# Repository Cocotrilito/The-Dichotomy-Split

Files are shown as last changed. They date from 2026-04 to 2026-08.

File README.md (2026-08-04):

# The -Dichotomy- Split

<p align="center">
  demo
</p>

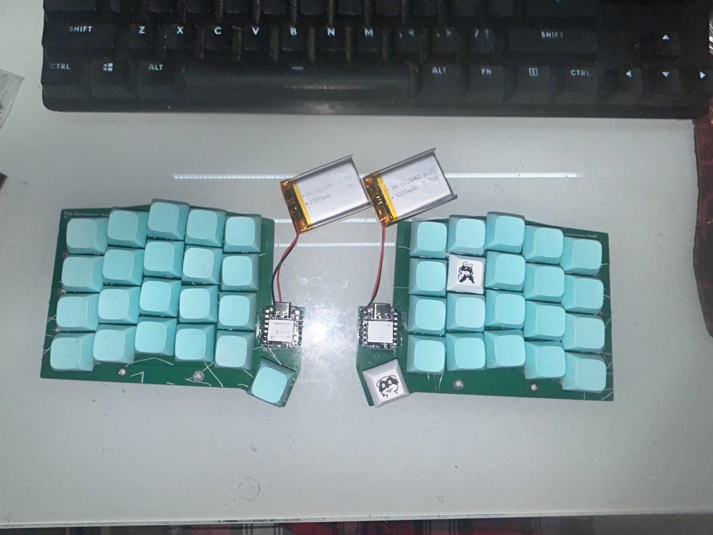
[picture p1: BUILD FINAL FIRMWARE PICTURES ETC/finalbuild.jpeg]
final build


[Download Final Firmware](<BUILD FINAL FIRMWARE PICTURES ETC/FinalFirmware.zip>)

An Split keyboard, created to understand new things like matrix and wireless things, and also from the feeling of being split, Im trying to become someone new but im still stuck in this hole, A tool for the transition... a bridge out of the hole.

## The reason behind this project...
Initially I wanted to prove myself I could go a little more deeper, what I mean Is that I had already made a macropad as my first hackclub project 4 months ago, and the split keyboard was the logical step, when I started with KiCad Fusion and coding.
everything was really hard im not saying today it isnt, but compared to how much I struggled 4 months ago, I can proudly say I have learned, and not just a little, but A LOT, and as I am writing this, throught my headphones KUNGFUPANDA theme song is blasting my
ears, this is the same song I used to play back and back again 4 months ago, and you see 4 months ago I was lost (im still kinda but not as I was), I was heartbroken, and without an actual purpose, and I saw I video on my feed talking about blueprint, this made
me really curious, and I started learning, and now here I am, well I wanted to learn about ZMK in my macropad I only did the QMK firmware but I really wanted to tryout ZMK, and was really cool!, also I wanted to make the projects that I thought were impossible
and to the Isaac of 4 months ago... Thanks!, you have really changed your life, and to the future Isaac... How are you doing? was it all worth it?... thanks for reading if you did! <3

## zmk repo
[ZMK code](https://github.com/Cocotrilito/zmk-config)
## layout


## Schematic Overview
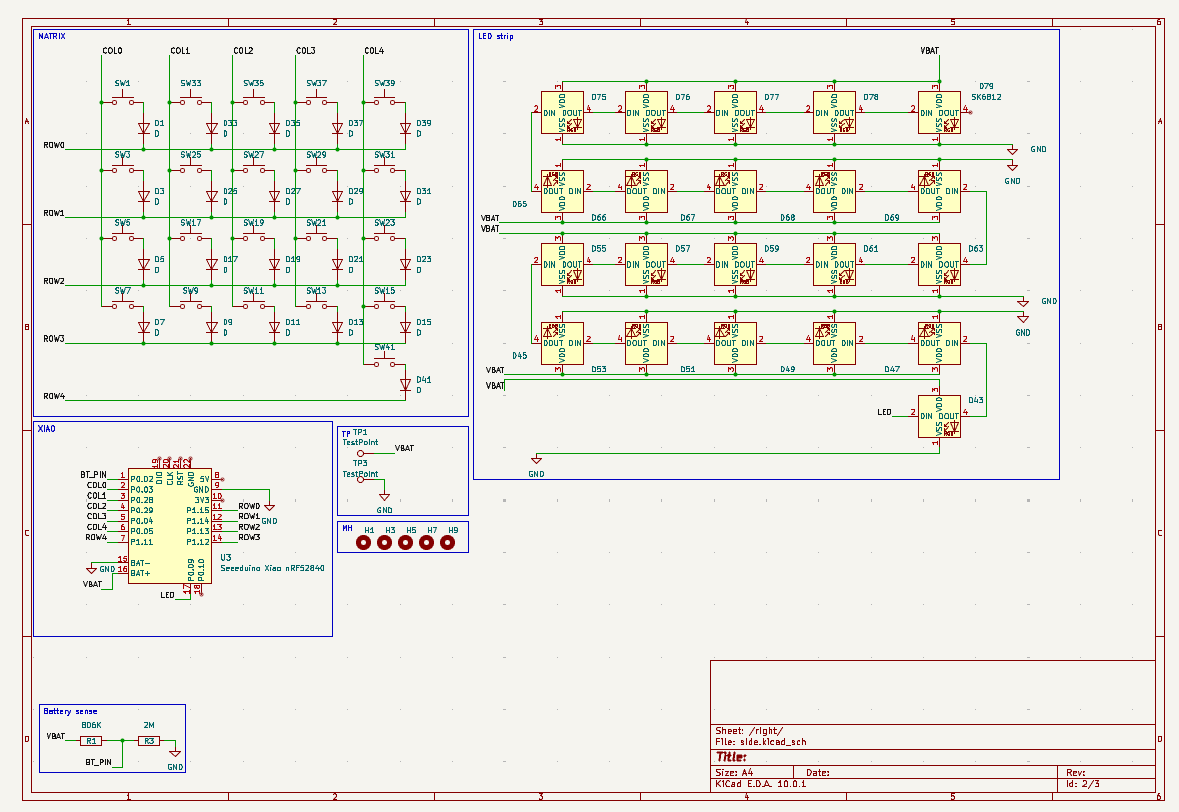
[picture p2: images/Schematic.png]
Schematic left


## PCB

<table>
  <tr>
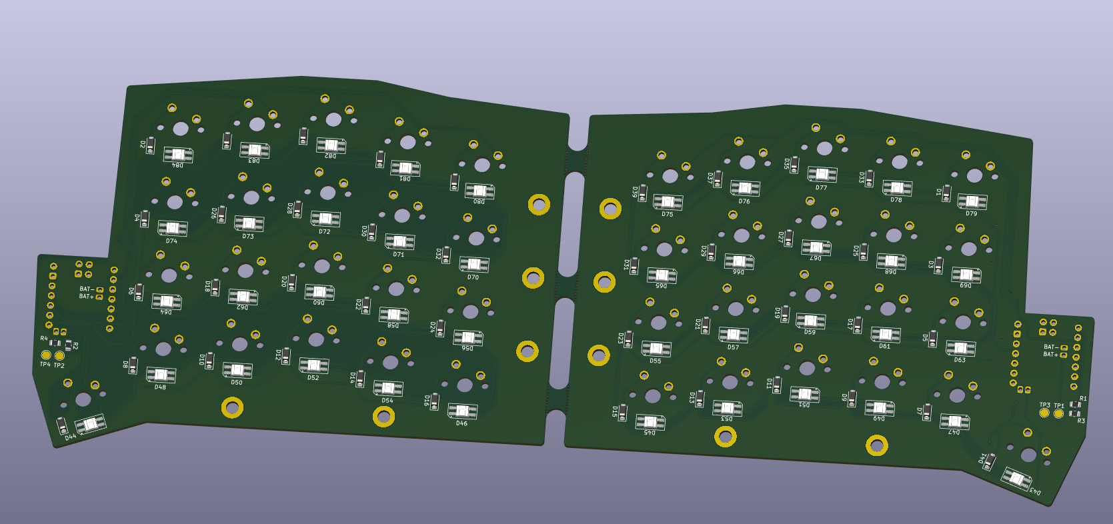
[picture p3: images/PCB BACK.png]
    <td align="center"><br><b>PCB OVERVIEW</b></td>
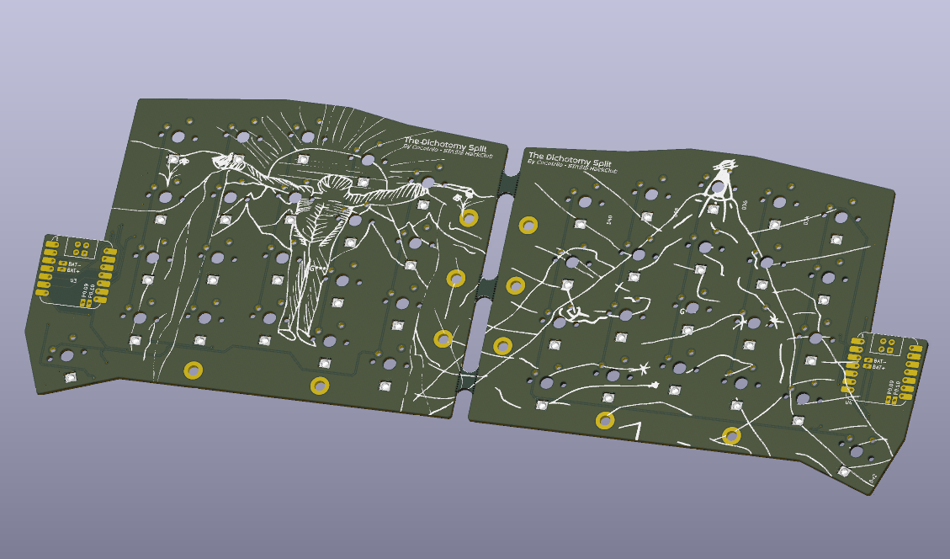
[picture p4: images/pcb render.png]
    <td align="center"><br><b>Render</b></td>
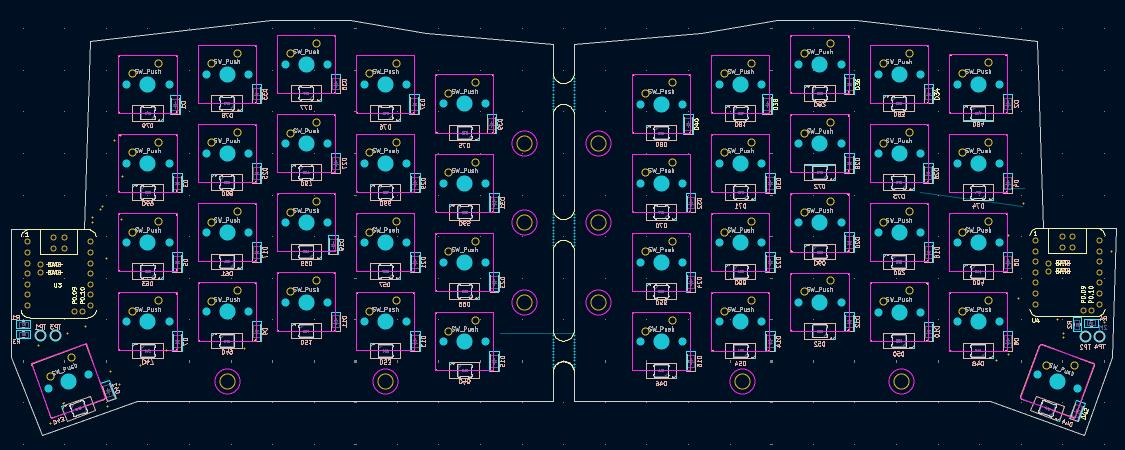
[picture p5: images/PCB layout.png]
    <td align="center"><br><b>PCB layout</b></td>
  </tr>
  <tr>
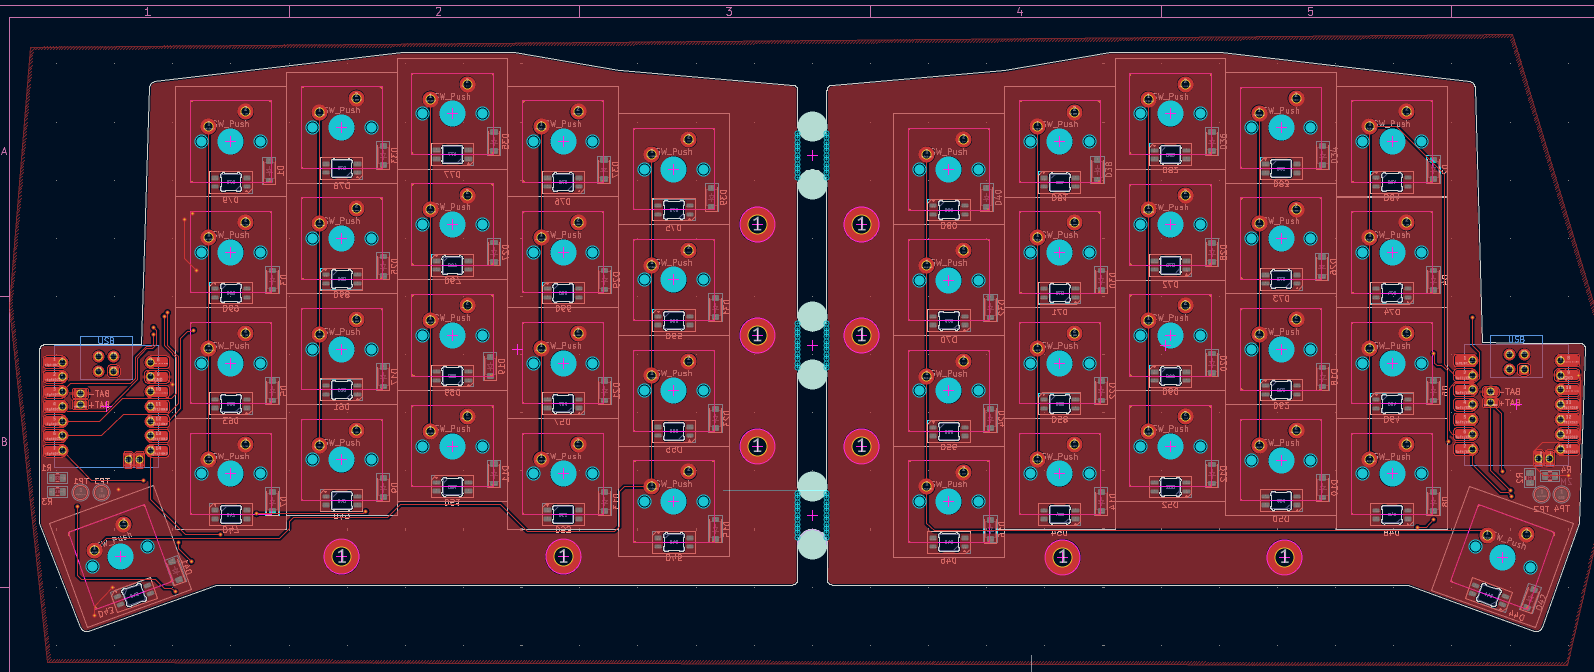
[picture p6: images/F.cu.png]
    <td align="center"><br><b>PCB Top</b></td>
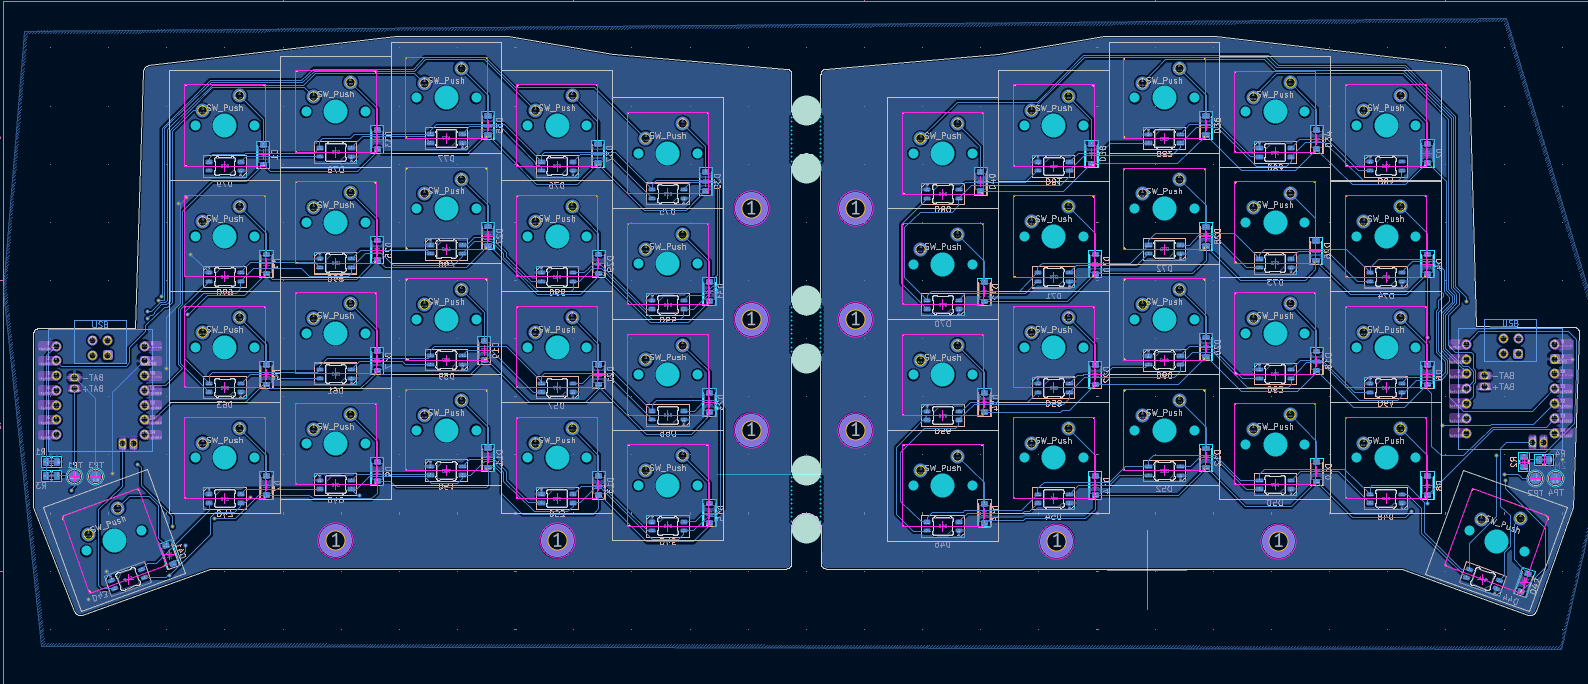
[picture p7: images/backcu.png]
    <td align="center"><br><b>PCB Back</b></td>
    <td></td>
  </tr>
</table>

## CAD Render
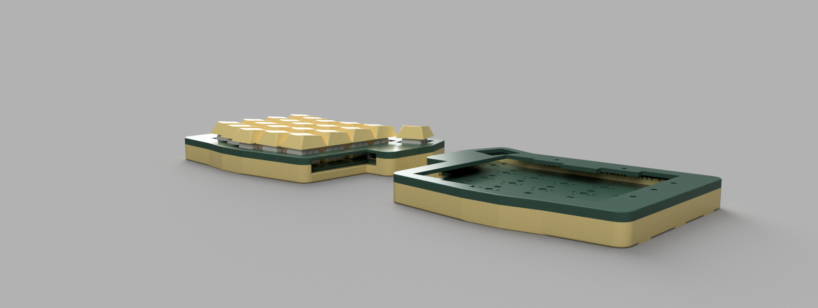
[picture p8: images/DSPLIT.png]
DSPLIT OVERVIEW

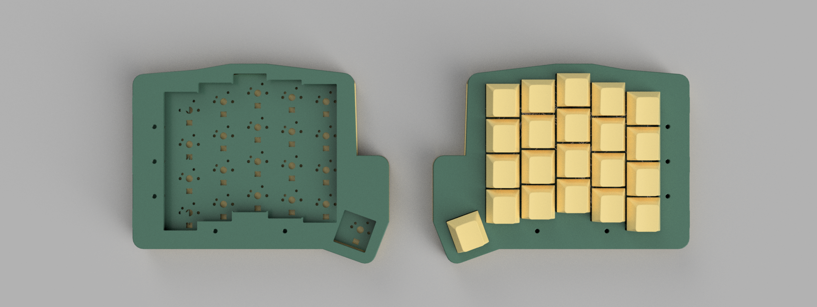
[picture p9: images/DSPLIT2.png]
DSPLIT TOP

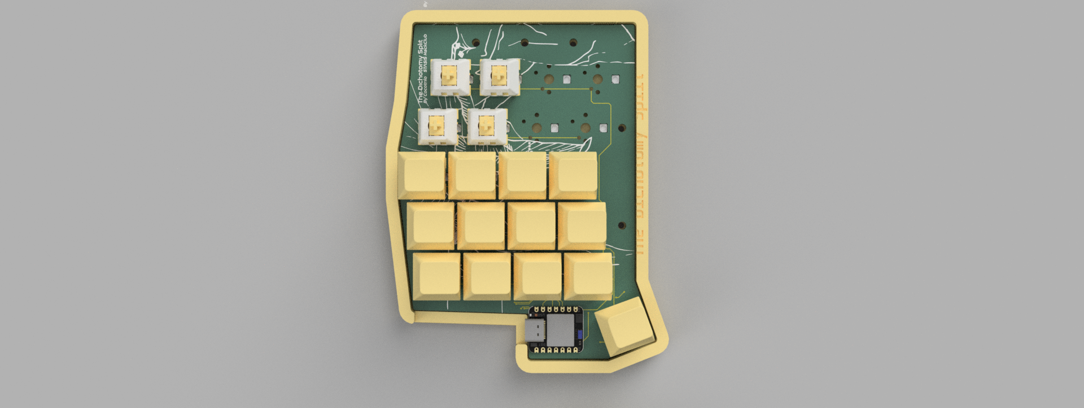
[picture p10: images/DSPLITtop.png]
DSPLIT CUT


## BOM

| Name | Purpose | Qty | Total Cost (USD) | Link |
| :--- | :--- | :---: | :---: | :--- |
| **1N4148W SOD-123** | Efficiency for pins in matrix, also avoids ghosting | 1 (set) | $1.31 | [AliExpress](https://www.aliexpress.us/item/3256810466885186.html) |
| **XDA Profile PBT Keycaps** | Ergonomics and feel | 1 (set) | $11.83 | [AliExpress](https://www.aliexpress.us/item/3256810402164930.html) |
| **Outemu Silent Switches** | Mechanical input (Tactile/Silent) | 1 (set) | $7.55 | [AliExpress](https://www.aliexpress.us/item/3256811652574937.html) |
| **LEDs SK6812 MINI-E** | Per-key RGB lighting (WS2812B compatible) | 1 (set) | $4.83 | [AliExpress](https://www.aliexpress.us/item/3256810305129996.html) |
| **PCB Manufacturing** | Custom designed PCBs for the split layout | 1 (set) | $14.60 | [JLCPCB] |
| **Seeed Studio XIAO nRF52840** | Main microcontrollers with BLE for wireless | 2 | $37.98 | [Amazon](https://www.amazon.com/gp/product/B09T9VVQG7/) |

## SPECIAL THANKS!
Thanks for reading! made possible with [STASIS by HackClubbers](http://stasis.hackclub.com/)

## You might also like!
[Voyager Panel](https://github.com/Cocotrilito/Voyager-Panel)
[HALO-0](https://github.com/Cocotrilito/HALO-0)

## final thanks :3
By cocotrilo made with luv (THIS ONE WAS WITH philosophical meaning) keep the grind <3

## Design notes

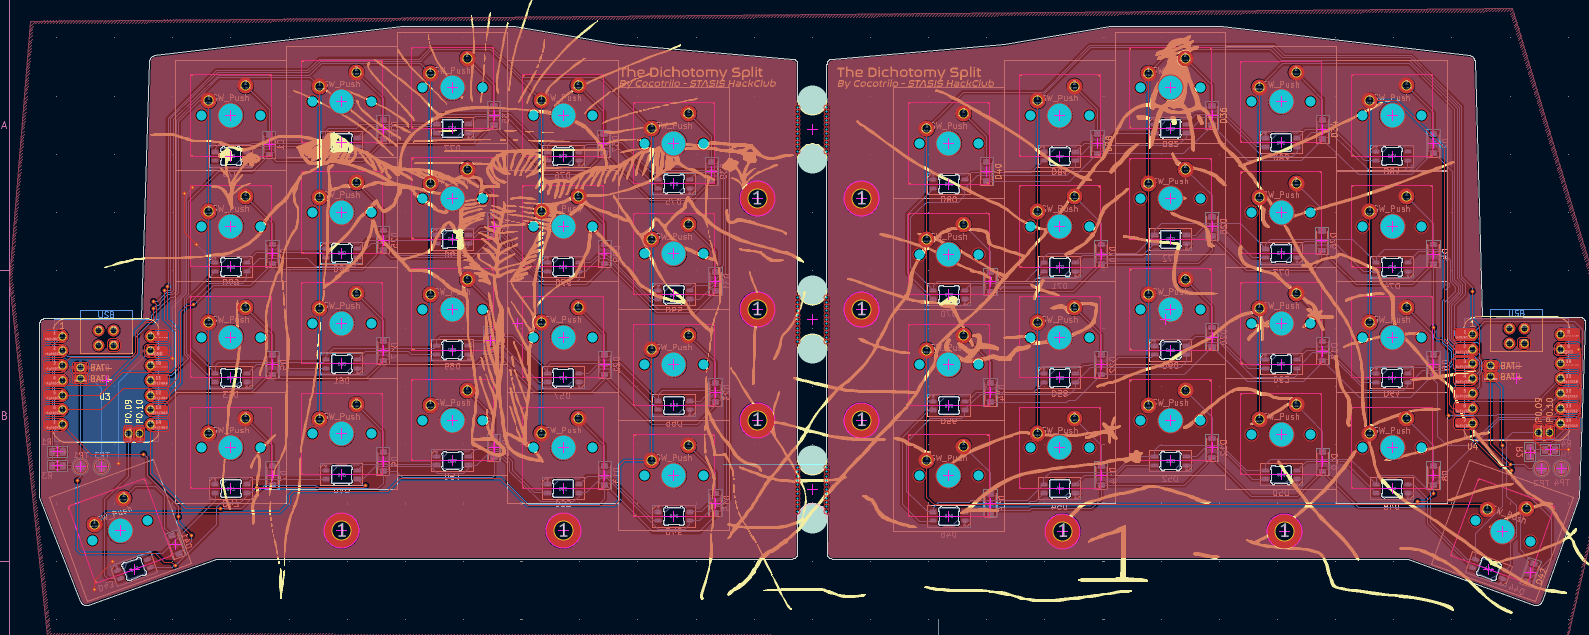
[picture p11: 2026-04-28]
images/overviewpcb.png

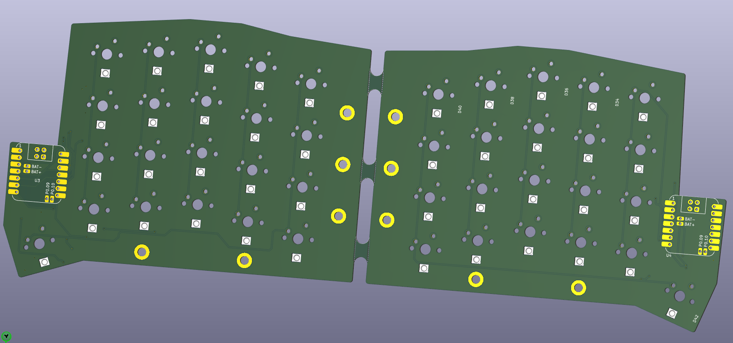
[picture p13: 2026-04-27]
images/PCB Front.png

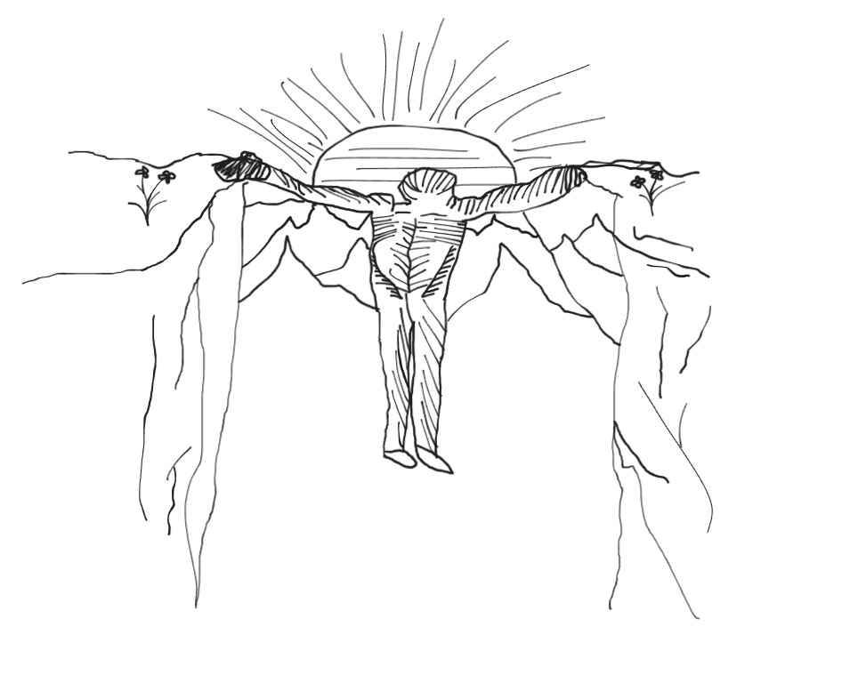
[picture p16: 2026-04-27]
images/art.png

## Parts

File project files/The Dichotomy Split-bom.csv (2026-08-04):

Name | Purpose | Quantity | Total Cost (USD) | Link | Distributor
1N4148W SOD-123 surface mount diode | Efficiency for pins in matrix, also avoids ghosting, and multiple inputs | 1 | 1.31 | https://www.aliexpress.us/item/3256810466885186.html?curPageLogUid=OGrmMMg8PsE2 | Aliexpress
Keycaps XDA PBT (50pcs) | Low-profile ergonomic keycaps for the switch matrix. | 1 | 9.24 | https://www.aliexpress.us/item/3256810402164930.html?mp=1 | Aliexpress
Mechanical Switches (50pcs) | Tactile input switches for the keyboard matrix. | 1 | 5.13 | https://www.aliexpress.us/item/3256811652574937.html?mp=1 | Aliexpress
LEDs SK6812 MINI-E (100pcs) | Per-key RGB lighting (WS2812B compatible protocol). | 1 | 4.83 | https://www.aliexpress.us/item/3256810305129996.html?mp=1 | Aliexpress
PCB Manufacturing (265x99mm) | Custom designed PCBs for the split layout | 1 | 14.60 |  | JLCPCB
Seeed Studio XIAO nRF52840 | Main microcontrollers with BLE for wireless split connectivity. | 2 | 37.98 | https://www.amazon.com/gp/product/B09T9VVQG7/ref=ox_sc_act_title_1?smid=A2OY3Y9CEYQQ5W | AMAZON
Resistor 2M Ohm 0805 (100pcs) | High-value resistor for the battery voltage divider circuit. | 1 | 3.05 | https://www.aliexpress.us/item/3256807764544932.html?mp=1 | Aliexpress
Resistor 806k Ohm 0805 (100pcs) | Precision resistor for the battery voltage divider circuit. | 1 | 3.05 | https://www.aliexpress.us/item/3256807764544932.html?mp=1 | Aliexpress

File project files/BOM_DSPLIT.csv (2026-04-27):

Part | Price | Quantity | Purpose | Link
Seeed Studio XIAO nRF52840 | 18.99 | 2 | Main microcontrollers with BLE for wireless split connectivity. | https://www.amazon.com/gp/product/B09T9VVQG7/ref=ox_sc_act_title_1?smid=A2OY3Y9CEYQQ5W
PCB Manufacturing (265x99mm) | 14.6 | 1 | Custom designed PCBs for the split layout
Keycaps XDA PBT (50pcs) | 9.24 | 1 | Low-profile ergonomic keycaps for the switch matrix. | https://www.aliexpress.us/item/3256810402164930.html?mp=1
Mechanical Switches (50pcs) | 5.13 | 1 | Tactile input switches for the keyboard matrix. | https://www.aliexpress.us/item/3256811652574937.html?mp=1
LEDs SK6812 MINI-E (100pcs) | 4.83 | 1 | Per-key RGB lighting (WS2812B compatible protocol). | https://www.aliexpress.us/item/3256810305129996.html?mp=1
Resistor 806k Ohm 0805 (100pcs) | 3.05 | 1 | Precision resistor for the battery voltage divider circuit. | https://www.aliexpress.us/item/3256807764544932.html?mp=1
Resistor 2M Ohm 0805 (100pcs) | 3.05 | 1 | High-value resistor for the battery voltage divider circuit. | https://www.aliexpress.us/item/3256807764544932.html?mp=1
 |  |  |  |  | Link

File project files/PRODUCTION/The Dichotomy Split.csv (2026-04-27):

Id | Designator | Footprint | Quantity | Comment | Supplier and ref
1 | D1, D2, D3, D4, D5, D6, D7, D8, D9, D10, D11, D12, D13, D14, D15, D16, D17, D18, D19, D20, D21, D22, D23, D24, D25, D26, D27, D28, D29, D30, D31, D32, D33, D34, D35, D36, D37, D38, D39, D40, D41, D42 | D_SOD-123 | 42 | D
2 | D43, D44, D45, D46, D47, D48, D49, D50, D51, D52, D53, D54, D55, D56, D57, D58, D59, D60, D61, D62, D63, D64, D65, D66, D67, D68, D69, D70, D71, D72, D73, D74, D75, D76, D77, D78, D79, D80, D81, D82, D83, D84 | LED_SK6812MINI-E_3.2x2.8mm_P1.5mm_ReverseMount | 42 | SK6812
3 | R1, R2 | R_0805_2012Metric | 2 | 806K
4 | R3, R4 | R_0805_2012Metric | 2 | 2M
5 | SW1, SW2, SW3, SW4, SW5, SW6, SW7, SW8, SW9, SW10, SW11, SW12, SW13, SW14, SW15, SW16, SW17, SW18, SW19, SW20, SW21, SW22, SW23, SW24, SW25, SW26, SW27, SW28, SW29, SW30, SW31, SW32, SW33, SW34, SW35, SW36, SW37, SW38, SW39, SW40, SW41, SW42 | SW_MX_1u | 42 | SW_Push
6 | TP1, TP2, TP3, TP4 | TestPoint_Pad_D2.0mm | 4 | TestPoint

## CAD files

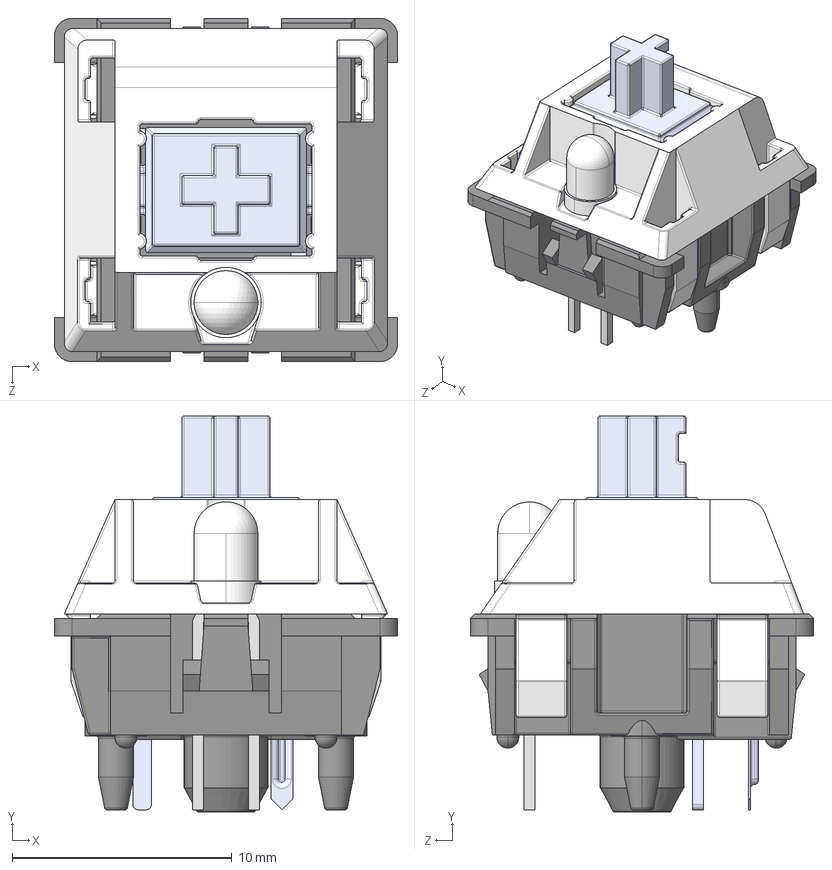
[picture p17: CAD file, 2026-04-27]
CAD/assets/cherry-mx-red-switch-1.snapshot.3/Cherry MX.STEP
15.6 x 18.0 x 15.6 mm
Bottom
Pulsador
Top
Pieza5^Cherry MX
Pin1
Pin2
Led 3mm_trans

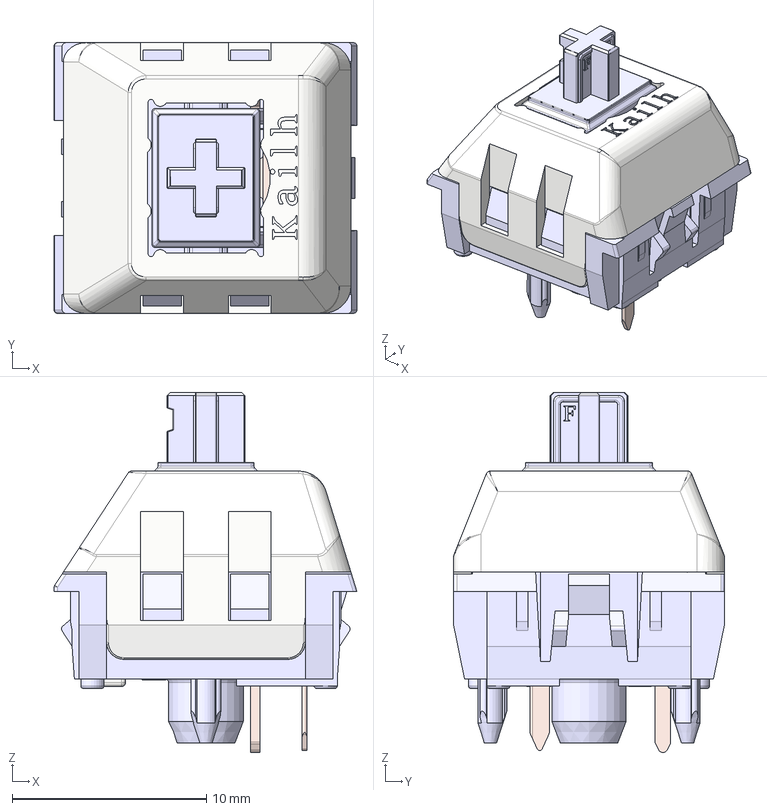
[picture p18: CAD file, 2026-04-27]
CAD/assets/kailh-polia-switch-cherry-mx-compatible-1.snapshot.1/Kailh Polia.step
15.6 x 14.0 x 18.5 mm
Housing
ThickContact
SpringContact
Stem
Lid

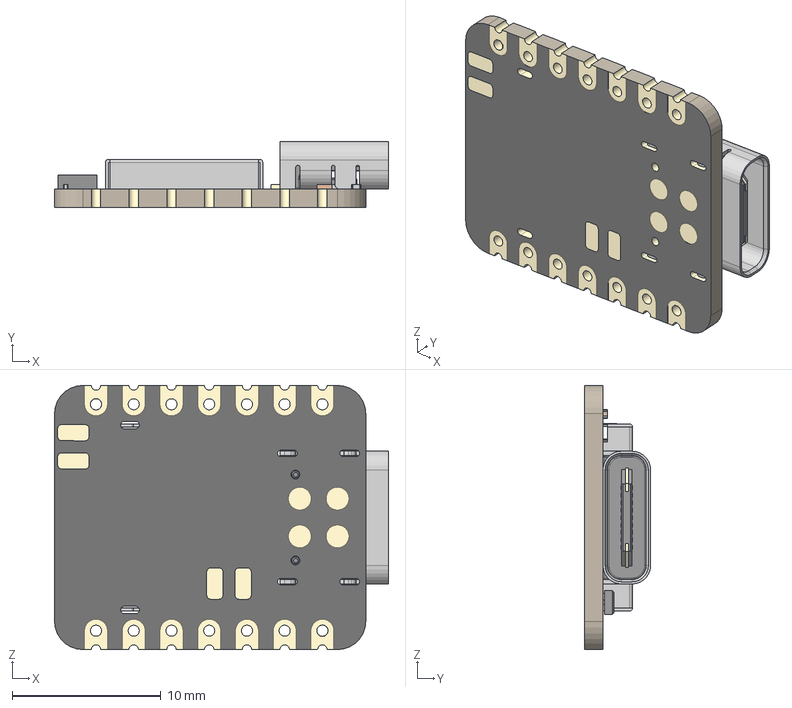
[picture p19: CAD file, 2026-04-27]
CAD/assets/seeed-studio-xiao-nrf52840-1.snapshot.5/XIAO-nRF52840 v15.step
22.5 x 4.46 x 17.8 mm
BOSS-EXTRUDE14_8_
BOSS-EXTRUDE7_4_
BOSS-EXTRUDE7_3_
BOSS-EXTRUDE14_4_
BOSS-EXTRUDE14_2_
BOSS-EXTRUDE14_11_
BOSS-EXTRUDE7_7_
BOSS-EXTRUDE14_9_
BOSS-EXTRUDE14_3_
BOSS-EXTRUDE14_7_
MIRROR2
BOSS-EXTRUDE14_5_
BOSS-EXTRUDE14_12_
BOSS-EXTRUDE7_8_
BOSS-EXTRUDE7_1_
BOSS-EXTRUDE14_10_
BOSS-EXTRUDE7_9_
BOSS-EXTRUDE14_6_
BOSS-EXTRUDE14_1_
BOSS-EXTRUDE7_6_
BOSS-EXTRUDE7_2_
CUT-EXTRUDE5
BOSS-EXTRUDE7_5_
Shield
Pins
CAP x 2
ANT1
Silkscreen
CAP 3
LED
USR
2 v1

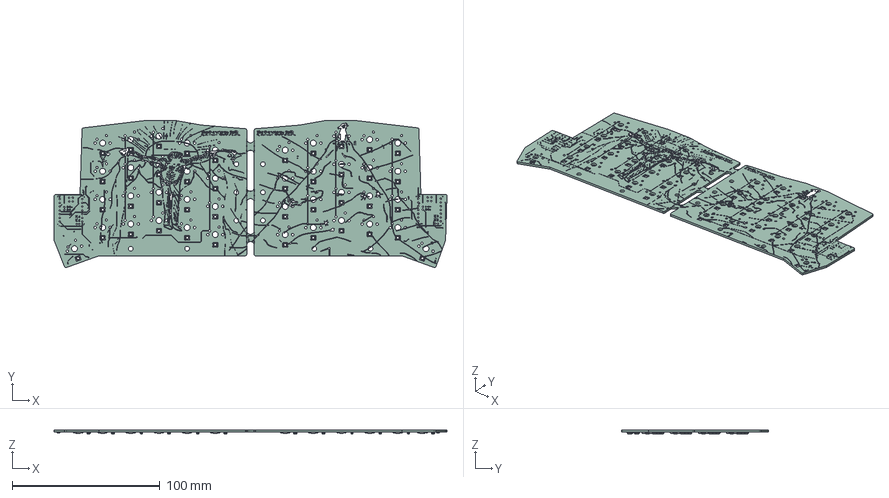
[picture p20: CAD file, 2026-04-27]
CAD/DSPLIT.step
265.9 x 99.6 x 2.93 mm
D_SOD-123 x 42
Pin1 x 42
Pin2 x 42
Pin3 x 42
Pin4 x 42
R_0805_2012Metric x 4
The Dichotomy Split_copper
The Dichotomy Split_via
The Dichotomy Split_silkscreen x 2
The Dichotomy Split_PCB

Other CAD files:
CAD/assets/cherry-mx-red-switch-1.snapshot.3/Cherry MX.IGS
CAD/assets/kailh-polia-switch-cherry-mx-compatible-1.snapshot.1/Kailh Polia.f3d

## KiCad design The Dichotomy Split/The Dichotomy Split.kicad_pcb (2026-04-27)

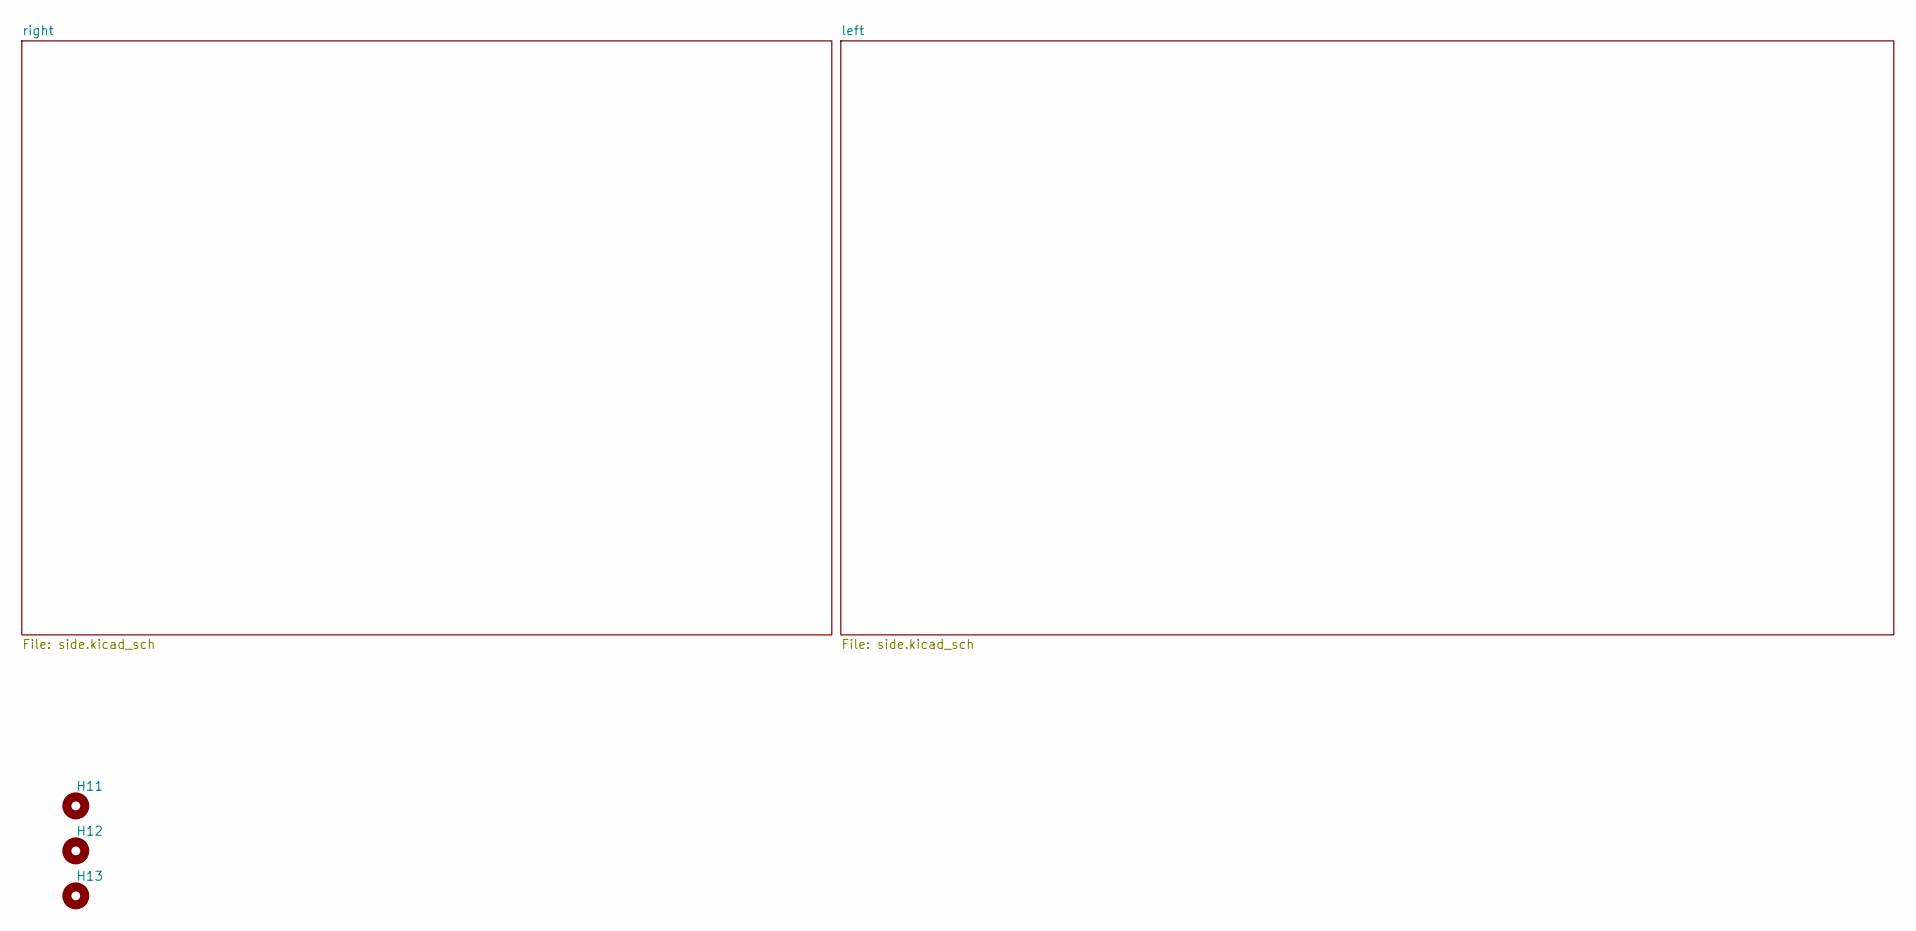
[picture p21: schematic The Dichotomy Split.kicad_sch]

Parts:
H11, H12, H13: MountingHole; mouse-bite-5mm-slot

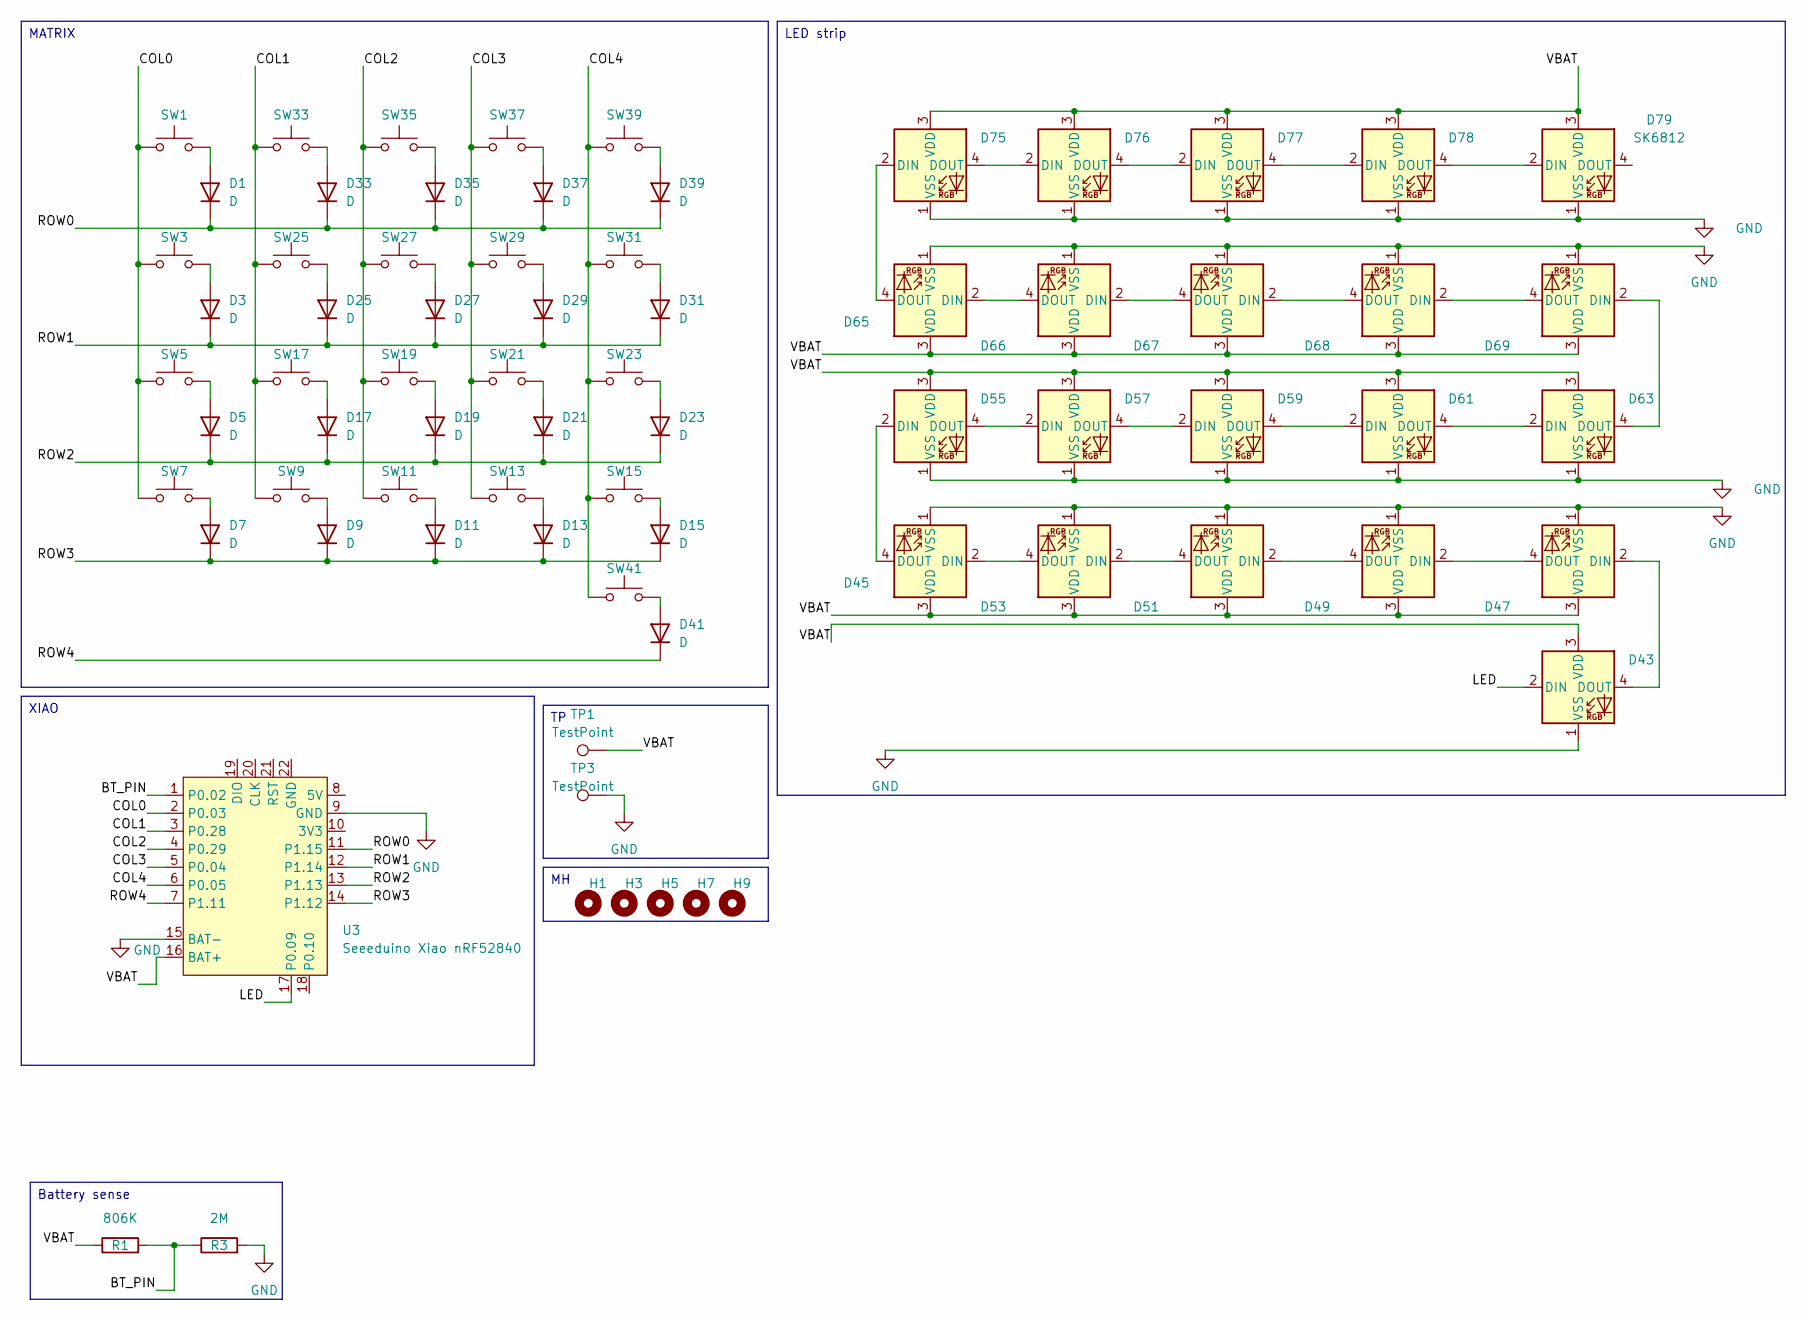
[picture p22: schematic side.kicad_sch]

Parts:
D1, D3, D5, D7, D9, D11, D13, D15, D17, D19, D21, D23, D25, D27, D29, D31, D33, D35, D37, D39, D41: D; D_SOD-123
D43, D45, D47, D49, D51, D53, D55, D57, D59, D61, D63, D65, D66, D67, D68, D69, D75, D76, D77, D78, D79: SK6812; LED_SK6812MINI-E_3.2x2.8mm_P1.5mm_ReverseMount
H1, H3, H5, H7, H9: MountingHole; MountingHole_3.2mm_M3_DIN965_Pad
R1: 806K; R_0805_2012Metric
R3: 2M; R_0805_2012Metric
SW1, SW3, SW5, SW7, SW9, SW11, SW13, SW15, SW17, SW19, SW21, SW23, SW25, SW27, SW29, SW31, SW33, SW35, SW37, SW39, SW41: SW_Push; SW_MX_1u
TP1, TP3: TestPoint; TestPoint_Pad_D2.0mm
U3: Seeeduino Xiao nRF52840; Xiao_nRF52840_ACH

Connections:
/right/BT_PIN: R1.2, R3.1, U3.1 (P0.02)
/right/COL0: SW1.1, SW3.1, SW5.1, SW7.1, U3.2 (P0.03)
/right/COL1: SW9.1, SW17.1, SW25.1, SW33.1, U3.3 (P0.28)
/right/COL2: SW11.1, SW19.1, SW27.1, SW35.1, U3.4 (P0.29)
/right/COL3: SW13.1, SW21.1, SW29.1, SW37.1, U3.5 (P0.04)
/right/COL4: SW15.1, SW23.1, SW31.1, SW39.1, SW41.1, U3.6 (P0.05)
/right/LED: D43.2 (DIN), U3.17 (P0.09)
/right/ROW0: D1.1 (K), D33.1 (K), D35.1 (K), D37.1 (K), D39.1 (K), U3.11 (P1.15)
/right/ROW1: D3.1 (K), D25.1 (K), D27.1 (K), D29.1 (K), D31.1 (K), U3.12 (P1.14)
/right/ROW2: D5.1 (K), D17.1 (K), D19.1 (K), D21.1 (K), D23.1 (K), U3.13 (P1.13)
/right/ROW3: D7.1 (K), D9.1 (K), D11.1 (K), D13.1 (K), D15.1 (K), U3.14 (P1.12)
/right/ROW4: D41.1 (K), U3.7 (P1.11)
/right/VBAT: D43.3 (VDD), D45.3 (VDD), D47.3 (VDD), D49.3 (VDD), D51.3 (VDD), D53.3 (VDD), D55.3 (VDD), D57.3 (VDD), D59.3 (VDD), D61.3 (VDD), D63.3 (VDD), D65.3 (VDD), D66.3 (VDD), D67.3 (VDD), D68.3 (VDD), D69.3 (VDD), D75.3 (VDD), D76.3 (VDD), D77.3 (VDD), D78.3 (VDD), D79.3 (VDD), R1.1, TP1.1 (1_1), U3.16 (BAT+)
GND: D43.1 (VSS), D45.1 (VSS), D47.1 (VSS), D49.1 (VSS), D51.1 (VSS), D53.1 (VSS), D55.1 (VSS), D57.1 (VSS), D59.1 (VSS), D61.1 (VSS), D63.1 (VSS), D65.1 (VSS), D66.1 (VSS), D67.1 (VSS), D68.1 (VSS), D69.1 (VSS), D75.1 (VSS), D76.1 (VSS), D77.1 (VSS), D78.1 (VSS), D79.1 (VSS), R3.2, TP3.1 (1_1), U3.9 (GND), U3.15 (BAT-); also elsewhere on the board
unnamed: D1.2 (A), SW1.2
unnamed: D3.2 (A), SW3.2
unnamed: D5.2 (A), SW5.2
unnamed: D7.2 (A), SW7.2
unnamed: D9.2 (A), SW9.2
unnamed: D11.2 (A), SW11.2
unnamed: D13.2 (A), SW13.2
unnamed: D15.2 (A), SW15.2
unnamed: D17.2 (A), SW17.2
unnamed: D19.2 (A), SW19.2
unnamed: D21.2 (A), SW21.2
unnamed: D23.2 (A), SW23.2
unnamed: D25.2 (A), SW25.2
unnamed: D27.2 (A), SW27.2
unnamed: D29.2 (A), SW29.2
unnamed: D31.2 (A), SW31.2
unnamed: D33.2 (A), SW33.2
unnamed: D35.2 (A), SW35.2
unnamed: D37.2 (A), SW37.2
unnamed: D39.2 (A), SW39.2
unnamed: D41.2 (A), SW41.2
unnamed: D43.4 (DOUT), D47.2 (DIN)
unnamed: D45.2 (DIN), D53.4 (DOUT)
unnamed: D45.4 (DOUT), D55.2 (DIN)
unnamed: D47.4 (DOUT), D49.2 (DIN)
unnamed: D49.4 (DOUT), D51.2 (DIN)
unnamed: D51.4 (DOUT), D53.2 (DIN)
unnamed: D55.4 (DOUT), D57.2 (DIN)
unnamed: D57.4 (DOUT), D59.2 (DIN)
unnamed: D59.4 (DOUT), D61.2 (DIN)
unnamed: D61.4 (DOUT), D63.2 (DIN)
unnamed: D63.4 (DOUT), D69.2 (DIN)
unnamed: D65.2 (DIN), D66.4 (DOUT)
unnamed: D65.4 (DOUT), D75.2 (DIN)
unnamed: D66.2 (DIN), D67.4 (DOUT)
unnamed: D67.2 (DIN), D68.4 (DOUT)
unnamed: D68.2 (DIN), D69.4 (DOUT)
unnamed: D75.4 (DOUT), D76.2 (DIN)
unnamed: D76.4 (DOUT), D77.2 (DIN)
unnamed: D77.4 (DOUT), D78.2 (DIN)
unnamed: D78.4 (DOUT), D79.2 (DIN)

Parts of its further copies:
D2, D4, D6, D8, D10, D12, D14, D16, D18, D20, D22, D24, D26, D28, D30, D32, D34, D36, D38, D40, D42: D; D_SOD-123
D44, D46, D48, D50, D52, D54, D56, D58, D60, D62, D64, D70, D71, D72, D73, D74, D80, D81, D82, D83, D84: SK6812; LED_SK6812MINI-E_3.2x2.8mm_P1.5mm_ReverseMount
H2, H4, H6: MountingHole; MountingHole_3.2mm_M3_DIN965_Pad
R2: 806K; R_0805_2012Metric
R4: 2M; R_0805_2012Metric
SW2, SW4, SW6, SW8, SW10, SW12, SW14, SW16, SW18, SW20, SW22, SW24, SW26, SW28, SW30, SW32, SW34, SW36, SW38, SW40, SW42: SW_Push; SW_MX_1u
TP2, TP4: TestPoint; TestPoint_Pad_D2.0mm
U4: Seeeduino Xiao nRF52840; Xiao_nRF52840_ACH

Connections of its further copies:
/left/BT_PIN: R2.2, R4.1, U4.1 (P0.02)
/left/COL0: SW2.1, SW4.1, SW6.1, SW8.1, U4.2 (P0.03)
/left/COL1: SW10.1, SW18.1, SW26.1, SW34.1, U4.3 (P0.28)
/left/COL2: SW12.1, SW20.1, SW28.1, SW36.1, U4.4 (P0.29)
/left/COL3: SW14.1, SW22.1, SW30.1, SW38.1, U4.5 (P0.04)
/left/COL4: SW16.1, SW24.1, SW32.1, SW40.1, SW42.1, U4.6 (P0.05)
/left/LED: D44.2 (DIN), U4.17 (P0.09)
/left/ROW0: D2.1 (K), D34.1 (K), D36.1 (K), D38.1 (K), D40.1 (K), U4.11 (P1.15)
/left/ROW1: D4.1 (K), D26.1 (K), D28.1 (K), D30.1 (K), D32.1 (K), U4.12 (P1.14)
/left/ROW2: D6.1 (K), D18.1 (K), D20.1 (K), D22.1 (K), D24.1 (K), U4.13 (P1.13)
/left/ROW3: D8.1 (K), D10.1 (K), D12.1 (K), D14.1 (K), D16.1 (K), U4.14 (P1.12)
/left/ROW4: D42.1 (K), U4.7 (P1.11)
/left/VBAT: D44.3 (VDD), D46.3 (VDD), D48.3 (VDD), D50.3 (VDD), D52.3 (VDD), D54.3 (VDD), D56.3 (VDD), D58.3 (VDD), D60.3 (VDD), D62.3 (VDD), D64.3 (VDD), D70.3 (VDD), D71.3 (VDD), D72.3 (VDD), D73.3 (VDD), D74.3 (VDD), D80.3 (VDD), D81.3 (VDD), D82.3 (VDD), D83.3 (VDD), D84.3 (VDD), R2.1, TP2.1 (1_1), U4.16 (BAT+)
GND: D44.1 (VSS), D46.1 (VSS), D48.1 (VSS), D50.1 (VSS), D52.1 (VSS), D54.1 (VSS), D56.1 (VSS), D58.1 (VSS), D60.1 (VSS), D62.1 (VSS), D64.1 (VSS), D70.1 (VSS), D71.1 (VSS), D72.1 (VSS), D73.1 (VSS), D74.1 (VSS), D80.1 (VSS), D81.1 (VSS), D82.1 (VSS), D83.1 (VSS), D84.1 (VSS), R4.2, TP4.1 (1_1), U4.9 (GND), U4.15 (BAT-); also elsewhere on the board
unnamed: D2.2 (A), SW2.2
unnamed: D4.2 (A), SW4.2
unnamed: D6.2 (A), SW6.2
unnamed: D8.2 (A), SW8.2
unnamed: D10.2 (A), SW10.2
unnamed: D12.2 (A), SW12.2
unnamed: D14.2 (A), SW14.2
unnamed: D16.2 (A), SW16.2
unnamed: D18.2 (A), SW18.2
unnamed: D20.2 (A), SW20.2
unnamed: D22.2 (A), SW22.2
unnamed: D24.2 (A), SW24.2
unnamed: D26.2 (A), SW26.2
unnamed: D28.2 (A), SW28.2
unnamed: D30.2 (A), SW30.2
unnamed: D32.2 (A), SW32.2
unnamed: D34.2 (A), SW34.2
unnamed: D36.2 (A), SW36.2
unnamed: D38.2 (A), SW38.2
unnamed: D40.2 (A), SW40.2
unnamed: D42.2 (A), SW42.2
unnamed: D44.4 (DOUT), D48.2 (DIN)
unnamed: D46.2 (DIN), D54.4 (DOUT)
unnamed: D46.4 (DOUT), D56.2 (DIN)
unnamed: D48.4 (DOUT), D50.2 (DIN)
unnamed: D50.4 (DOUT), D52.2 (DIN)
unnamed: D52.4 (DOUT), D54.2 (DIN)
unnamed: D56.4 (DOUT), D58.2 (DIN)
unnamed: D58.4 (DOUT), D60.2 (DIN)
unnamed: D60.4 (DOUT), D62.2 (DIN)
unnamed: D62.4 (DOUT), D64.2 (DIN)
unnamed: D64.4 (DOUT), D74.2 (DIN)
unnamed: D70.2 (DIN), D71.4 (DOUT)
unnamed: D70.4 (DOUT), D80.2 (DIN)
unnamed: D71.2 (DIN), D72.4 (DOUT)
unnamed: D72.2 (DIN), D73.4 (DOUT)
unnamed: D73.2 (DIN), D74.4 (DOUT)
unnamed: D80.4 (DOUT), D81.2 (DIN)
unnamed: D81.4 (DOUT), D82.2 (DIN)
unnamed: D82.4 (DOUT), D83.2 (DIN)
unnamed: D83.4 (DOUT), D84.2 (DIN)

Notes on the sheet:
MATRIX
LED strip
XIAO
Battery sense

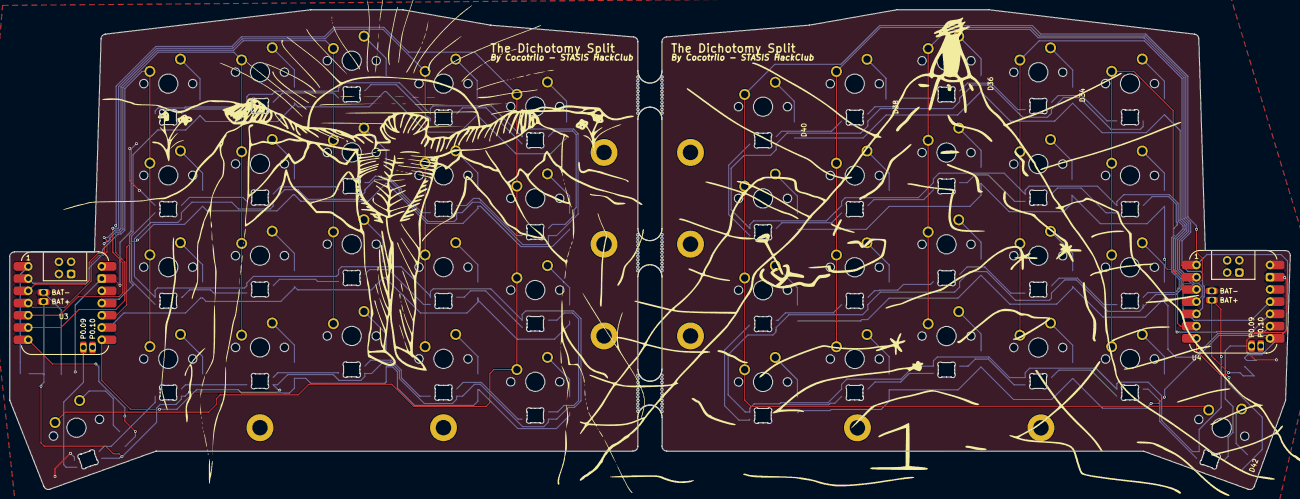
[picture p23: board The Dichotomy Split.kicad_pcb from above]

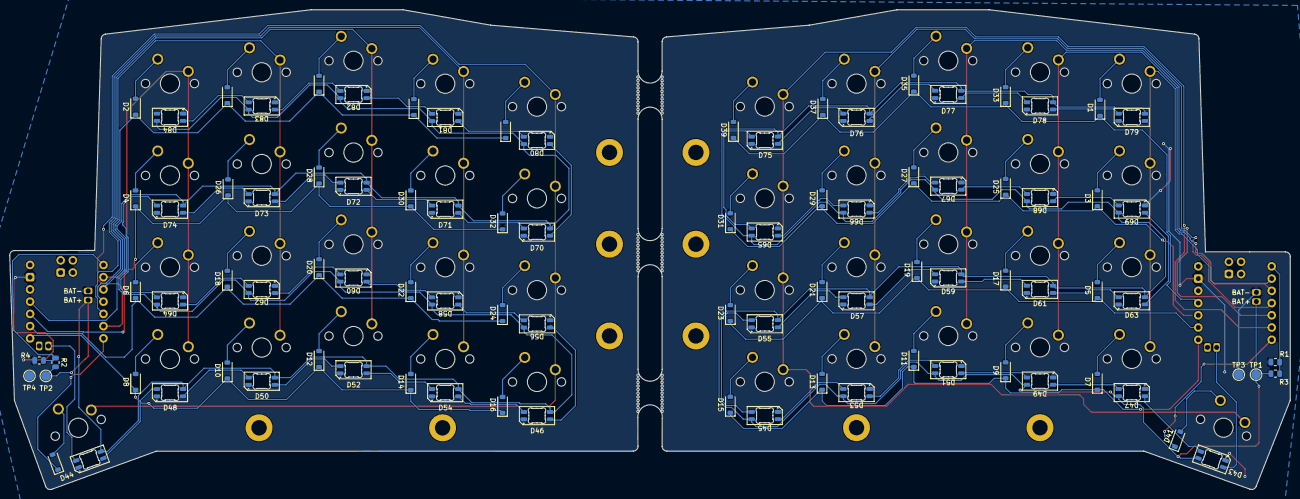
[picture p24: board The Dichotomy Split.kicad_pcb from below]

Board: 2 copper layers, 265.9 x 99.6 mm, 149 parts (92 on the bottom side), 109 nets.

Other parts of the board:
H1#2, H3#2: MountingHole; MountingHole_3.2mm_M3_DIN965_Pad

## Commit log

2026-04-26 SETUP LIBS
    [The Dichotomy Split.kicad_pcb, The Dichotomy Split.kicad_sch]
2026-04-27 Schematic AND pcb finished!
    [The Dichotomy Split.kicad_pcb, The Dichotomy Split.kicad_sch, side.kicad_sch]
2026-04-27 pictures CAD BOM GERBERS ZMK FIRMWARE
    [BOM_DSPLIT.csv, Cherry MX.IGS, Cherry MX.STEP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]
2026-04-28 Create README.md for -Dichotomy- Split keyboard project
    Added detailed project overview, including reasons for creation, schematic, PCB images, BOM, and acknowledgments.
2026-04-28 Add PCB Back image to README
2026-04-28 Revise BOM section with detailed item descriptions
2026-08-04 final things
    [The Dichotomy Split-bom.csv]
2026-08-04 Forzar la subida del FinalFirmware.zip
